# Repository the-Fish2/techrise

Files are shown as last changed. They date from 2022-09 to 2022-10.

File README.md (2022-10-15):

# NASA Techrise Challenge Work
Nishka Kacheria

## Before Flight ##

### Hypothesis ###
Pollution is concentrated at lower altitudes, due to denser particles sinking. However, there is the possibility of environmental factors, such as thermal inversion, causing a different result. 

### Data ###
* Determining the percentage of air pollution
* Detailed quantification of air pollution resulting in improved targeting/ scoping of possible solutions
* Determination of the percentage of air pollution that is below cloud level contributing to getting recycled into the hydrologic cycle and thereby to water pollution. 
* Correlation between living at higher altitudes and prevalence of lung cancer and other similar health implications.
* Qualitative implication of air pollution. This can be used to raise awareness and rally efforts to address air pollution, similar to: endangered species photo archive, glacial melt photographs, library of lost sounds of animals.

### Fun Issues ###
* Working with computers
  * Video decoder issues
  * Memory issues - my computer can render videos stored on the hard disk drive, but not as reliably from an SD card
  * Writing Python programs, and subsequently, CircuitPy code that runs on the microprocessor
* Wiring up microprocessors and sensors
  * Including how MISO/MOSI ports and the I2C interface work
  * Handling multiple data streams with limited TX ports
  * Disassembling off the shelf products to extract individual components
  * Regulating circuits using pull-up resistors (more current is not always good!)
  * Soldering & heat shrink tubing
  * Wire stripping & tinning
  * Graduating from gobs of flux to clean connections
  * Painfully learning how not to burn myself again
  * Taking care of soldering implements
* 3-D printing
  * How to design 3-D models, accounting for printer limitations, supports and overhangs
  * 3-D printer issues such as print bed adhesion, extruder blockage, delamination
  * Sanding to make last minute adjustments to fit sharp 3-D printed corners in a rounded capsule
* Hardening for extreme pressures and temperatures
  * Most 3-D infill patterns can’t handle decreased atmospheric pressures
  * Epoxy works, tape residue melts
  * Popsicle sticks absorb humidity and skew readings

### Code ###
Clone the repository and save it to the metro, in addition to missing files. 
Certain files, ie TRSim Raven, require certain other physical parts (sent from NASA) to work.
The code itself works with a Dashcam (hacked), a SPS 30 particulate matter sensor, an SD Card breakout board, and a BME 680/688 AQI. 
Leave the .fseventsd and Trashes files on your Metro M4 Express, these are in addition. 
Lib files from Adafruit's documentation. 
The Dashcam does not have code, for formatting it to allow a 7 hr flight, format a 64GB card to Fat32 and it should work. 

### Specs ###
Weighs 527.3 g / 1.16 lb
Size: 40 x 40 x 80 inch / 101.6 x 101.6 x 203.2 cm box
5 V
0.27 A

Data Parameters collected:
* Vehicle_Time
* Vehicle_Altitude
* Temperature (C)
* Gas (ohms)
* Humidity (%)
* Pressure (hPa)
* 40um particles
* 10um particles
* pm10 standard
* pm100 standard
* pm25 standard
* 25um particles
* 100um particles
* particles 05um
* pm40 standard
* Image (color of sky)

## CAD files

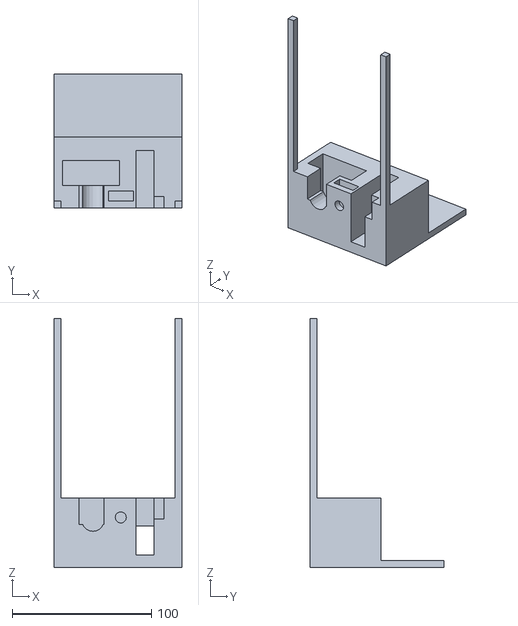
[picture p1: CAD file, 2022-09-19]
Fantastic Turing (1).stl
92.0 x 96.0 x 179.0

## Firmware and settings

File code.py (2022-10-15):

import trsim_raven
import board
import busio
import sdcardio
import storage
import time
import adafruit_vc0706
import adafruit_bme680
from adafruit_sps30.i2c import SPS30_I2C

i2c = board.I2C()
pmsensor = SPS30_I2C(i2c, 0x69)
aqsensor = adafruit_bme680.Adafruit_BME680_I2C(i2c, 0x77)

#bme increments by 4 degrees, thus vals subtracted

spi = board.SPI()
cs = board.D7
sdcard = sdcardio.SDCard(spi, cs)
vfs = storage.VfsFat(sdcard)
storage.mount(vfs, "/sd")

with open("/sd/temps.txt", "a") as f:
    f.write("Altitude, Time, Temperature (C), Gas (ohms), Humidity (%), Pressure (hPa), 40um particles, 10um particles, pm10 standard, pm100 standard, pm25 standard, 25um particles, 100um particles, particles 05um, tps, pm40 standard")
    f.write("\n")
    f.close()


TRsim = trsim_raven.Simulator(pbf_pin=board.D2, go_pin=board.D3)

print(TRsim.time_secs)
currTemp = aqsensor.temperature - 4

LAND = 0
RISING = 1
FLOATING = 2
DESCENDING = 3
curr_events = LAND
prev_events = curr_events

num_packets = 0

RISE_TH = -2
FLOAT_TH = 4
DSCND_TH = 5

while True:
    TRsim.update()
    if (TRsim.streaming):
        if TRsim.new_data:
            num_packets += 1

            data=TRsim.data
            curr_vd = TRsim.velocity_down

            if curr_vd < RISE_TH:
                curr_events = RISING
            elif curr_vd >= RISE_TH and curr_vd < DSCND_TH and curr_events != LAND:
                curr_events = FLOATING
            elif curr_vd >= DSCND_TH:
                curr_events = DESCENDING
            else:
                curr_events = LAND

            if curr_events != prev_events:
                prev_events = curr_events


            if (num_packets % 10 == 1):
                altitude = TRsim.altitude
                if curr_events == RISING:
                    with open("/sd/temps.txt", "a") as f:
                        print(altitude)
                        f.write("{}, {}, ".format(altitude, TRsim.time_secs))
                        try:
                            f.write("{}, {}, {}, {}, ".format((aqsensor.temperature-4), aqsensor.gas, aqsensor.humidity, aqsensor.pressure))
                            currTemp = aqsensor.temperature - 4
                        except:
                            f.write("AQsensorerror ")
                        if (currTemp > -18):
                            try:
                                results = pmsensor.read()
                                for key in results:
                                    f.write(str(results[key]) + ", ")
                            except:
                                f.write("PMsensorerror ")
                        f.write("\n")
                        f.close()

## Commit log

2022-06-30 Create i2c.py
    src: https://github.com/kevinjwalters/Adafruit_CircuitPython_SPS30/blob/master/adafruit_sps30/i2c.py
    add to adafruit lib
2022-07-01 Update code.py
    Fixing file size issues? So preventing overriding files and all
    now images will be saved as image123.jpg where 123 is the altitude
    potentially need to fix this for text file? seems unnecessary though
    [code.py]
2022-08-15 Fixing aqi printing
2022-09-07 Sensor Code w/out TRSim, w/out cam
2022-09-07 Sensor code w/out camera
    Includes PM sensor, TRSim, SD card, BME688
2022-09-08 Allowed for wider temp range for pm sensor
2022-09-09 -4 degrees for BME calibration
2022-09-19 3-D Printed Mounting
    [Fantastic Turing (1).stl]
2022-10-12 Added try/except so that if the pm sensor fails, then quit
    [code.py]
2022-10-13 Fixed need for if loops
    [code.py]
2022-10-15 Fixed try catch + temperature settings
    [code.py]
2022-10-15 Rename aqsdcode to past_code/AQI_SD_code
    Also VC0706 camera code, commented out - does not work with shared TX port of TRSim, so not useful for this project
2022-10-15 Rename code2 to past_code/AQI_SPS30_SD_code
    Leaves commented out camera code. Does not account for temperature discrepancies/errors, as that is not necessary at lower altitudes.
2022-10-15 Added Wiring Diagram
    SCL/SDA ports need to be shared (i2c interface), use pull-up resistors as it doesn't hinder the BME but is necessary for the PM sensor
